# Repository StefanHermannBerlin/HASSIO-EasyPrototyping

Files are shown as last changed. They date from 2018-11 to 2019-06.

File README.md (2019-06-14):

# General Sensor/Actuator for Hassio
 
This readme is organised in three parts:

- Overview
- Building the General Sensor/Actuator
- Configuration

## Overview

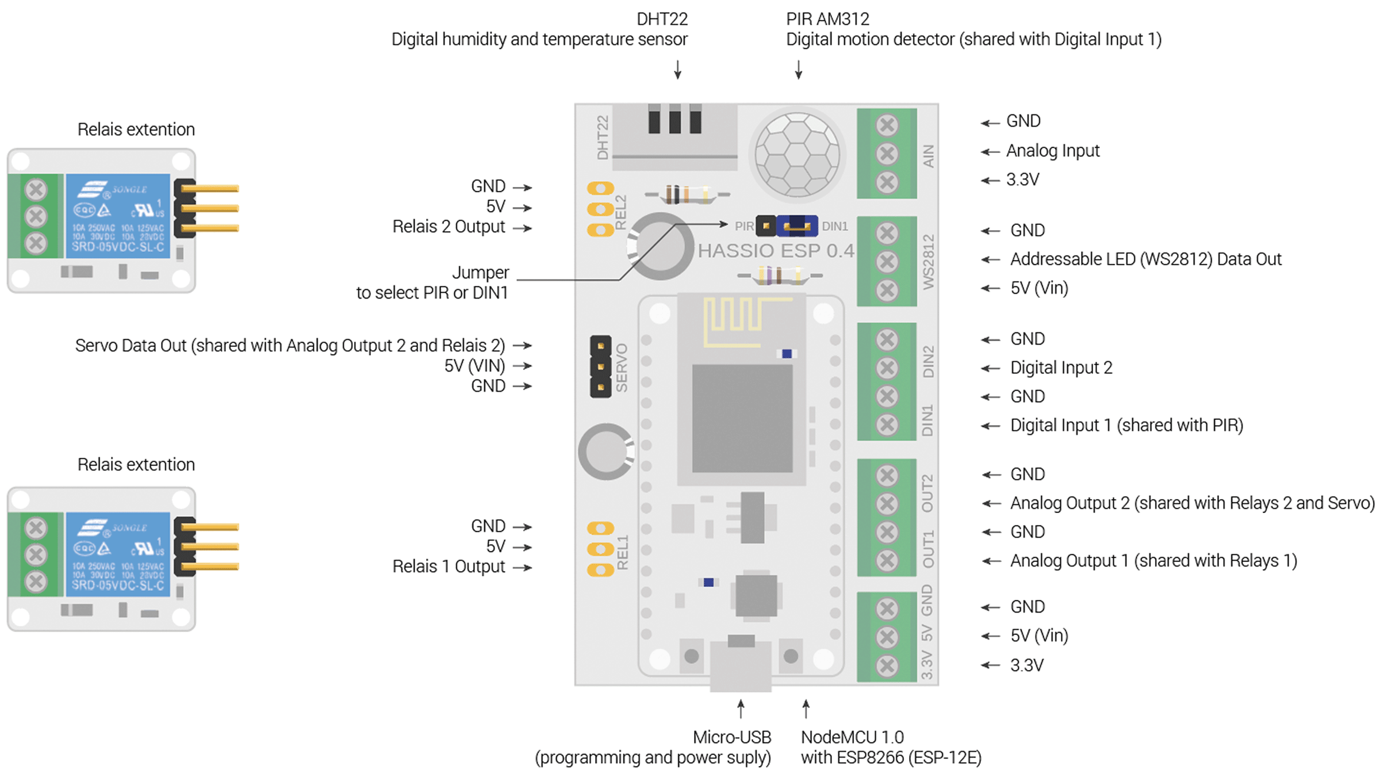
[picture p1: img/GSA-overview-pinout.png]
GSA Pinout


The General Sensor/Actuator (GSA) is a modular device to create functional smart home prototypes to test ideas with users.

It connects to the Home Assistant platform which allows us to prototype smart home applications. Home Assistant can connect to several available devices and makes automation and interoperability possible.

The GSA consists of a NodeMCU, a wifi enabled microcontroller, screw terminals connect sensors and actors to it, a DHT22 temperature and humidity sensor, a PIR sensor (motion sensor), a terminal to connect a servo motor to and two connections for relay modules.

The GSA is powered by a USB power supply.

#### Pins
- 1x Analog input (e.g. light sensors, potentiometers, water sensors)
- 1x WS2812 connector (addressable LEDs)
- 2x Digital input (e.g. buttons, switches, D1 shared through jumper with a digital motion sensor)
- 2x Analog output (PWM, e.g. dimmable lights, motors - can be used as digital outputs to attach Relais extension boards)
- 2x Relais output for extension boards (shared with the analog outputs)
- 1x Servo connector (shared with Analog output 2)

The configuration is mainly done through the firmware, the software running the GSA. The firmware is transferred through the Arduino IDE.

## Building the General Sensor/Actuator

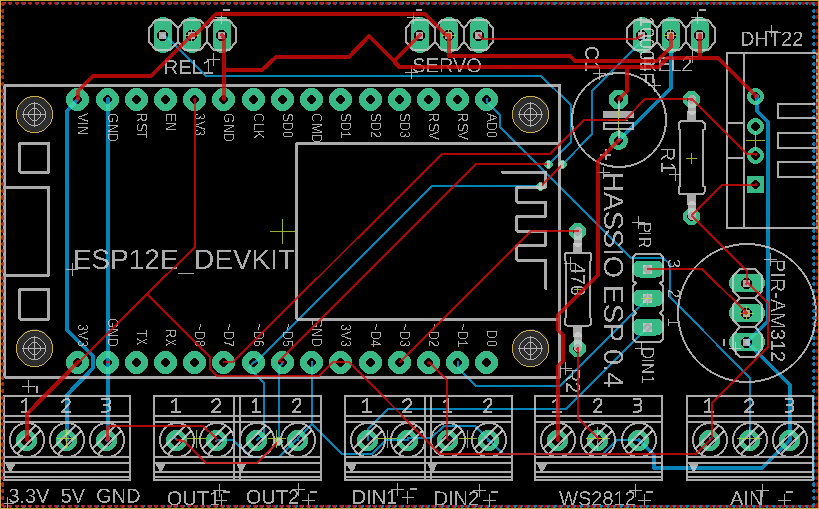
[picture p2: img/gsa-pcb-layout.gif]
GSA PCB Layout


BOM
- 2x 90° 1x3 pin header female
- Resistors: 1x 10k, 1x 470 ohms
- 2x 1x3 pin header male
- 2x 1x15 pin header female
- 2x 1x3 pin header female
- 1x AM312 digital PIR
- 3x screw terminals 3 pins
- 3x screw terminals 4 pins
- 1x DHT22
- 1x electrolytic capacitor 1000uF
- 1x NodeMCU (ESP 12E Module)

Building the GSA is relatively easy. You can order the PCBs using the files contained in the Eagle-folder of this repository from any PCB manufacturing service. Once you have the PCBs solder the following components. I suggest the following order:

- 2x 90° pin headers REL1 and REL2 (2x 1x3 pins female)
- Resistor RE1 with 10k and RE2 with 470 ohms
- Pin headers for SERVO and the jumper (2x 1x3 pins male)
- Pin header for the ESP module (2x 1x15 pins female)
- I recommend to solder a pin header for the digital PIR (1x 1x3 pins female)
- screw terminals (3x 3 pins, 2x 4 pins)
- DHT22
- Capacitor 1000uF

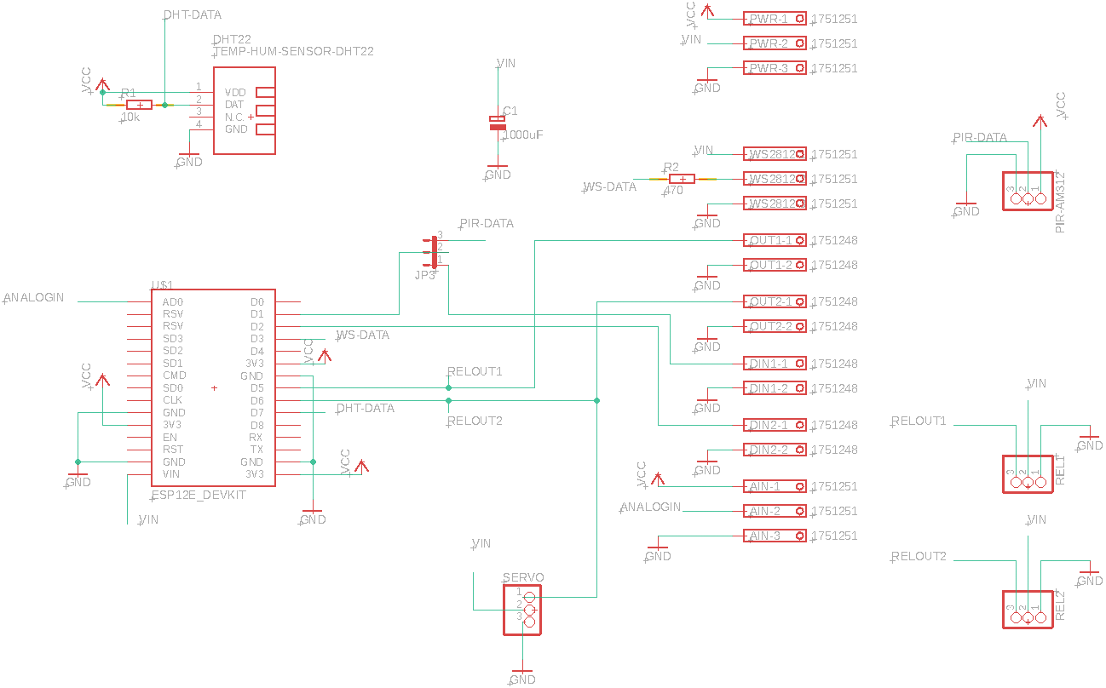
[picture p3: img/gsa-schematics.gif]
GSA Schematics


## GSA configuration

Now, let's connect a General Sensor/Actuator (GSA) to Hass.io. Three simple steps are needed:

Upload a configured firmware to the GSA
Change the configuration.yaml file of your Hass.io installation
Restart Hass.io
1. Upload a configured firmware to the GSA

(I assume you already configured the Arduino software. Otherwise, start here: Set up the Arduino IDE.)

Open the file gsa.ino (You can get it from Github) and fill out the network and security lines. In the device configuration, choose a unique device ID for the GSA. This can be as simple as «LivingRoomFirstFloor».

```
        
/************ Configuration for network and security ******************/

#define wifi_ssid "myWifiName"                        // type your WIFI name in here
#define wifi_password "myWifiPassword"                // your WIFI password
#define mqtt_server "192.168.1.211"                   // the IP of your mqtt broker, e.g. from your Raspbarry Pi running Hassio and the MQTT broker
#define mqtt_user "HassioUserName"                    // your mqtt user name, in the easiest case your Hassio username
#define mqtt_password "HassioPassword"                // your mqtt user password, in the easiest case your Hassio password
#define OTApassword "myFOTApassword"                  // defined by you! and used to upload new firmware from the Arduino-Software (FOTA: Firmware Over The Air)

/************ Device configuration ******************/

#define SENSORNAME "myGeneralSensorActuator007"       // choose an unique device ID for the gsa

boolean digital1opener = true;                        // defines, if digital 1 is opener or closer
boolean digital2opener = true;                        // defines, if digital 2 is opener or closer

boolean digitalIndicatorLED1 = true;                  // if true show indicator light for digital 1
boolean digitalIndicatorLED2 = true;                  // if true show indicator light for digital 1

boolean relay1 = false;                               // if true, relay can be used, if false analog output can be used (if false, don't connect a relais, it will be damaged by the pwm output!!)
boolean relay2 = false;                               // if true, relay can be used, if false analog output can be used (if false, don't connect a relais, it will be damaged by the pwm output!!)

boolean servo = false;                                // if true, servo can be used, if false analog output can be used (if false, don't connect a servo, it may get damaged by the pwm output!!)

boolean showCommunicationFlash = true;                // if true led flashes on data transmission

float diffAnalog = 20;                                // On how much difference should the analog sensore react on?

(this is just a code snipped from the original file gsa.ino)
    
```  
    
You can leave the rest unchanged and simply upload the program to your GSA.

Home Assistant configuration

Open the «configuration.yaml» file in the Configurator. Input the following lines to the light section. (There must only be one «light:» entry. If it already exists, put the child nodes in the existing light section.

```
light:
  - platform: mqtt
    schema: json
    name: "myGSA1 AOut1"  
    state_topic: "myGSA1/aout1"  
    command_topic: "myGSA1/aout1/set"  
    brightness: true   
    rgb: false  
    qos: 0
  - platform: mqtt
    schema: json
    name: "myGSA1 AOut2"  
    state_topic: "myGSA1/aout2"  
    command_topic: "myGSA1/aout2/set"  
    brightness: true   
    rgb: false  
    qos: 0
  - platform: mqtt
    schema: json
    name: "myGSA1 LED"  
    state_topic: "myGSA1"  
    command_topic: "myGSA1/set"  
    brightness: true  
    rgb: true  
    qos: 0  
```    

Now, input the following lines to the sensor section. (There must only be one «sensor:» entry. If it already exists, put the child nodes in the existing sensor section.

```
sensor:
  - platform: mqtt  
    state_topic: "myGSA1"  
    name: "myGSA1 Temperature"  
    unit_of_measurement: "°C"  
    value_template: '{{ value_json.temperature | round(1) }}'  
  - platform: mqtt  
    state_topic: "myGSA1"  
    name: "myGSA1 Humidity"  
    unit_of_measurement: "%"  
    value_template: '{{ value_json.humidity | round(1) }}'  
  - platform: mqtt  
    state_topic: "myGSA1"  
    name: "myGSA1 Analog In"
    value_template: '{{ value_json.analog }}'  

binary_sensor:
  - platform: mqtt
    state_topic: "myGSA1"
    name: "myGSA1 Digital1 In"
    value_template: '{{ value_json.digital1 }}'
    payload_on: "1"
    payload_off: "0"
  - platform: mqtt
    state_topic: "myGSA1"
    name: "myGSA1 Digital2 In"
    value_template: '{{ value_json.digital2 }}'
    payload_on: "1"
    payload_off: "0"
```

Save the configuratoin.yaml and open the groups.yaml file and input the following lines.

```
myGSA1_card: 
  name: Sensor/Actuator 1
  entities: 
    - sensor.myGSA1_temperature
    - sensor.myGSA1_humidity
    - sensor.myGSA1_analog_in
    - binary_sensor.myGSA1_digital1_in
    - binary_sensor.myGSA1_digital2_in
    - light.myGSA1_led
    - light.myGSA1_aout1
    - light.myGSA1_aout2
```

Now reboot your system. After the reboot, you should see the myGSA1 card in Hass.io.

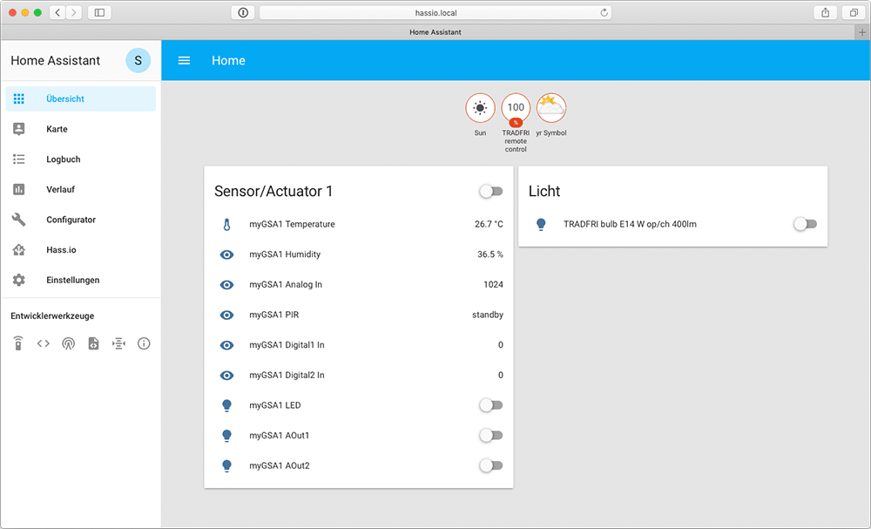
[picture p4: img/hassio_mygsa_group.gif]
GSA Group Card


I hope you find this setup as useful as I do. Have fun!

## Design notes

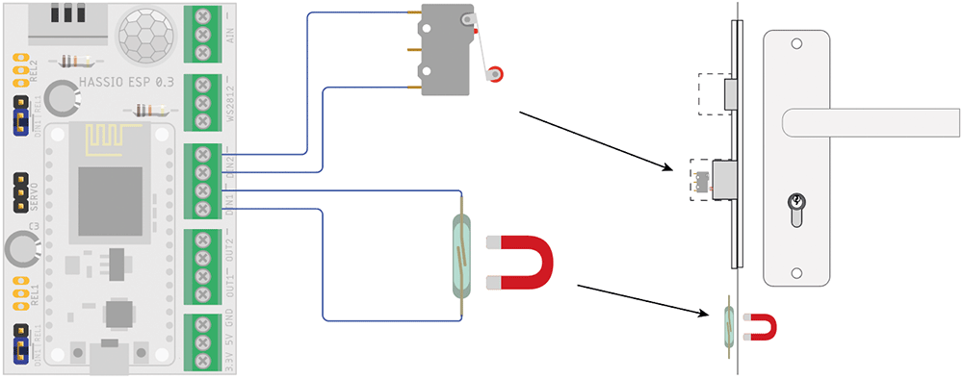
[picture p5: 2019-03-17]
img/esp-door-hardware.gif

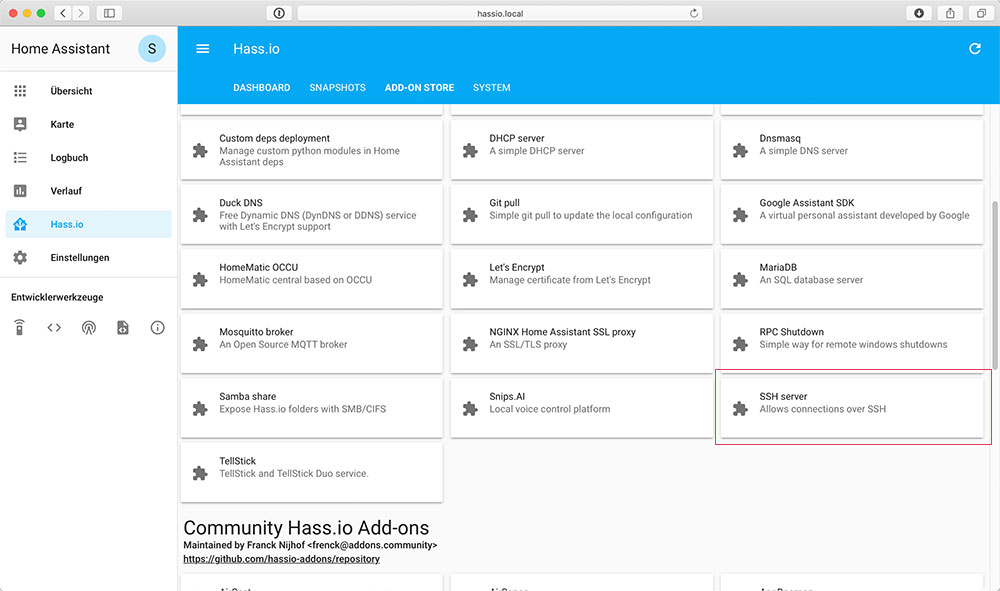
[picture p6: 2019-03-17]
img/hassio_enable_ssh.jpg

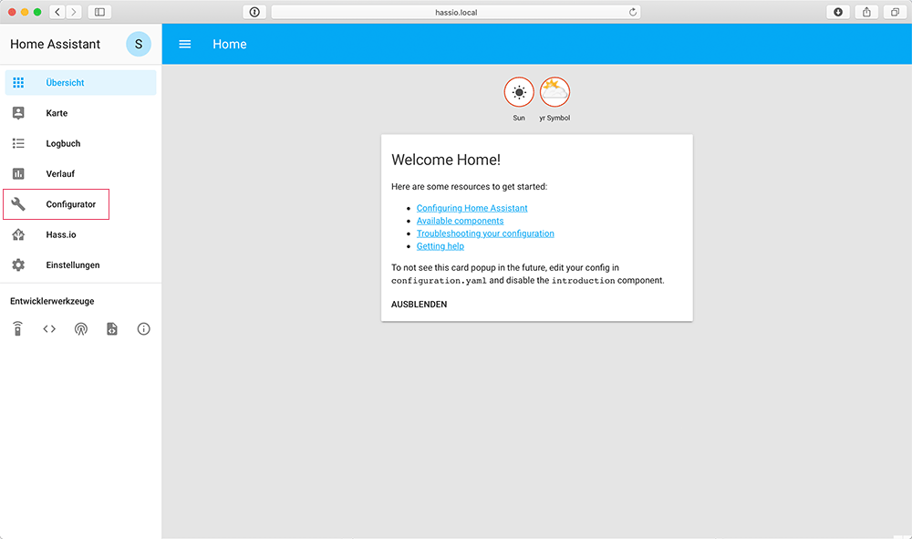
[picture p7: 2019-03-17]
img/hassio-configurator-menu.gif

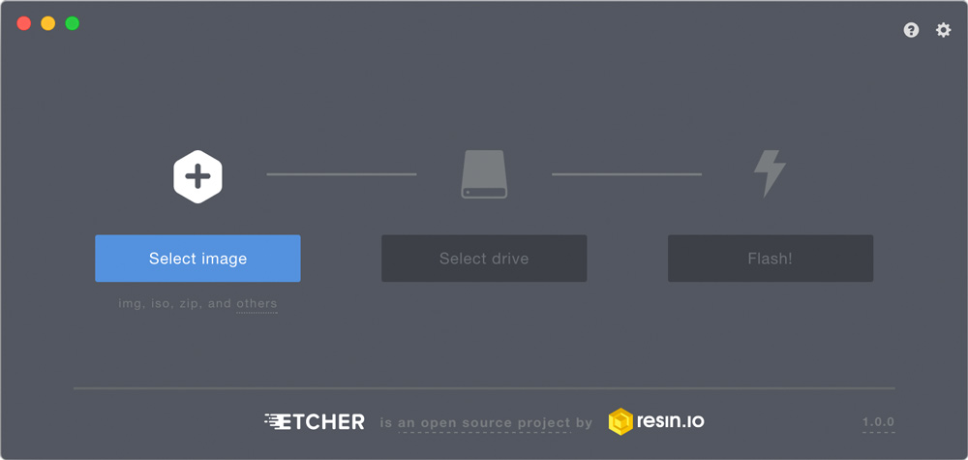
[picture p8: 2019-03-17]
img/screenshot-etcher.jpg

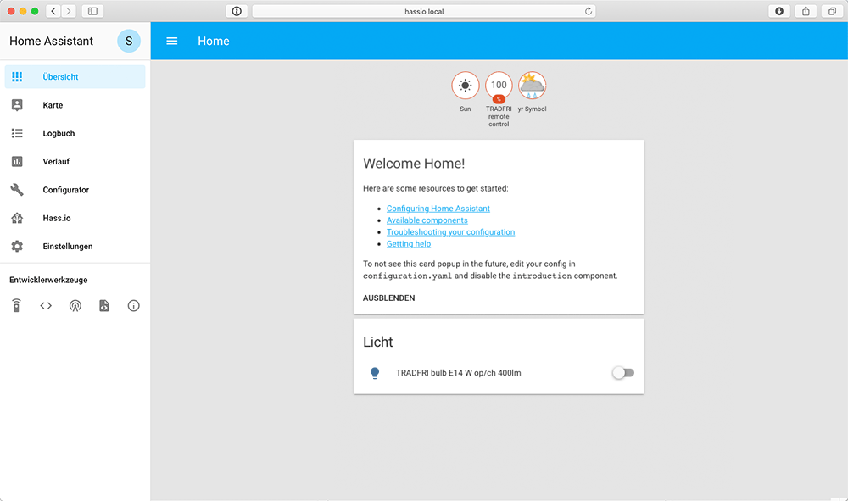
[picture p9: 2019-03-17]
img/hassio_tradfri_card.gif

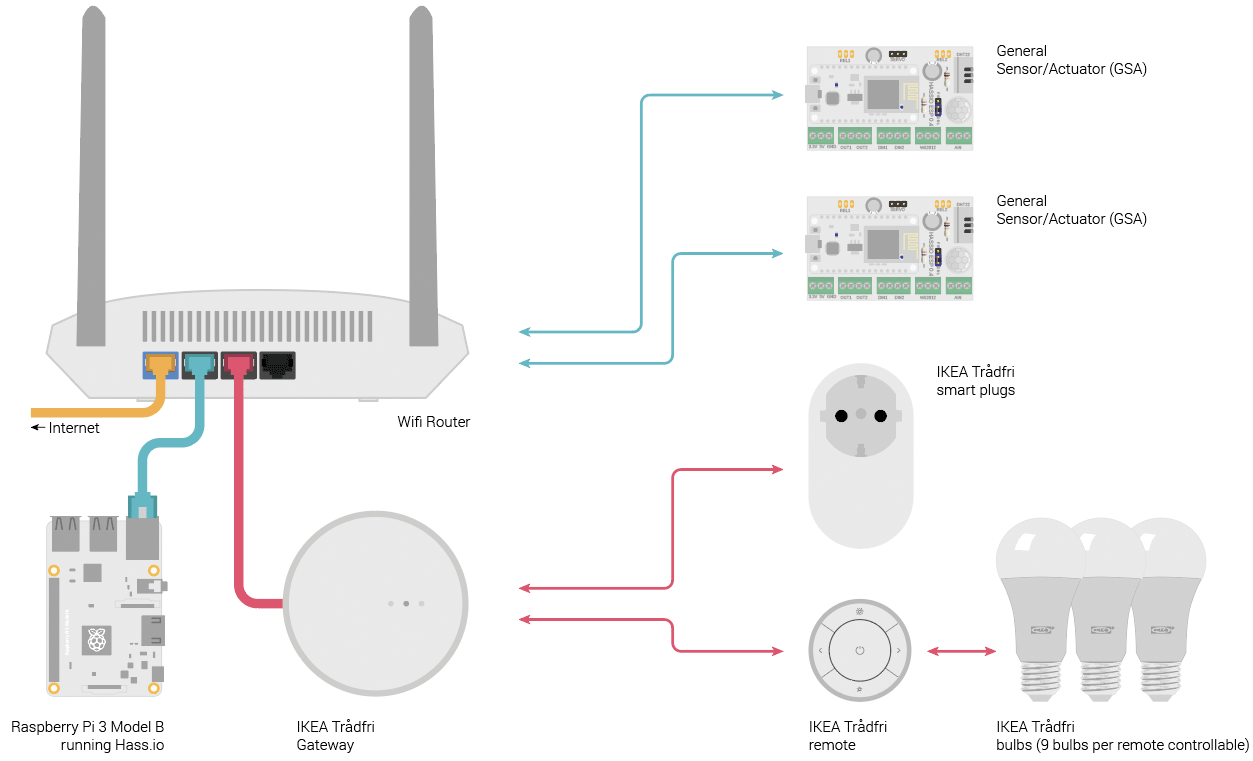
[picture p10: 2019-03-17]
img/prototyping-environment.gif

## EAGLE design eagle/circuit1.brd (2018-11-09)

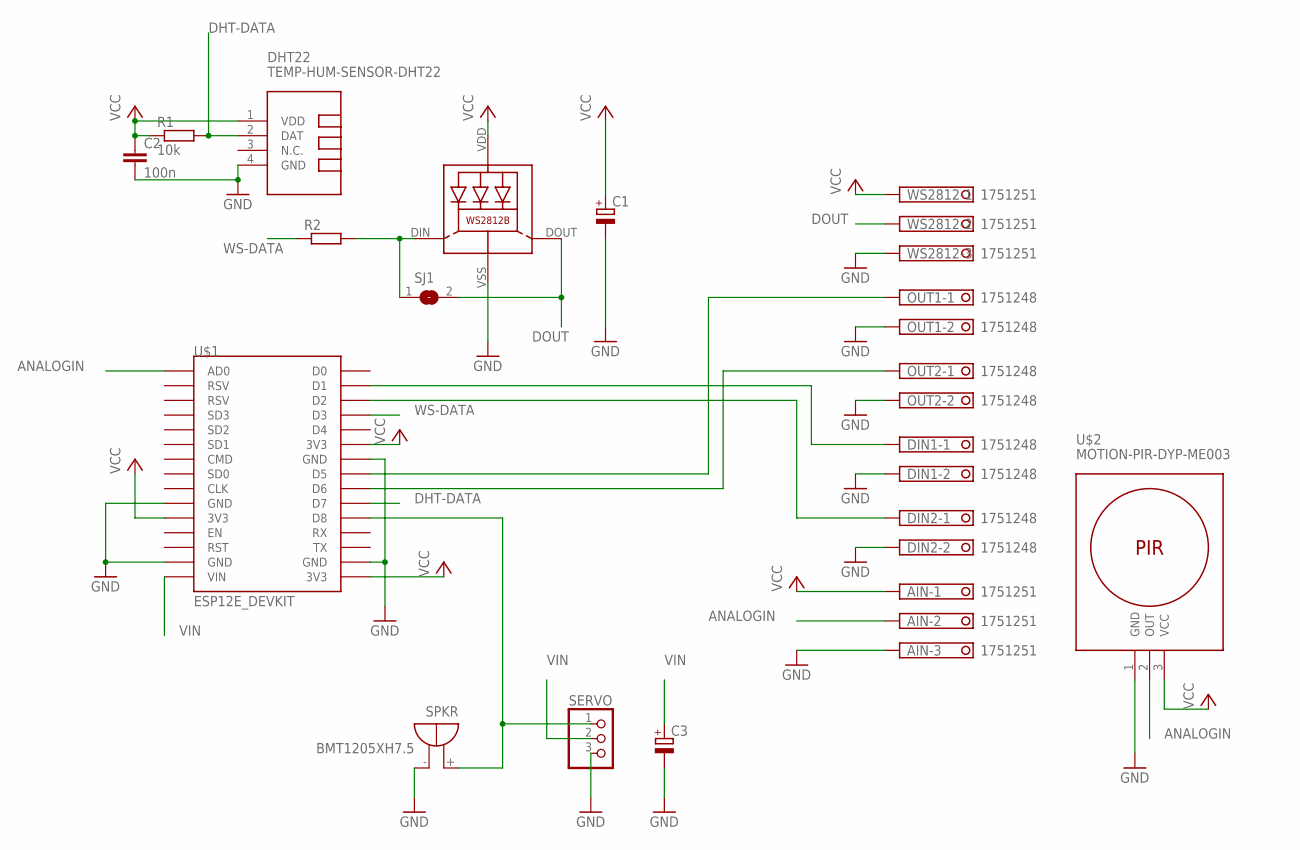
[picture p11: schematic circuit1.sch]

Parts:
AIN: 1751251
C1, C3: CPOL-EUE2.5-7; E2,5-7
C2: 100n; C0805
DHT22: TEMP-HUM-SENSOR-DHT22
DIN1, DIN2: 1751248
LED1: WS2812B
OUT1, OUT2: 1751248
R1: 10k; 0207/10
R2: R0207/10; 0207/10
SERVO: PINHD-1X3; 1X03
SJ1: SJ
SPKR: BMT1205XH7.5
U$1: ESP12E_DEVKIT
U$2: MOTION-PIR-DYP-ME003
WS2812: 1751251

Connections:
ANALOGIN: AIN.2, U$1.AD0, U$2.2 (OUT)
DHT-DATA: DHT22.2 (DAT), R1.2, U$1.D7
DOUT: LED1.DOUT (DO), SJ1.2, WS2812.2
GND: AIN.3, C1.-, C2.2, C3.-, DHT22.4 (GND), DIN1.2, DIN2.2, LED1.VSS (GND), OUT1.2, OUT2.2, SERVO.3, SPKR.-, U$1.GND@0 (GND), U$1.GND@1 (GND), U$1.GND@2 (GND), U$1.GND@3 (GND), U$2.1 (GND), WS2812.3
unnamed: SERVO.1, SPKR.+, U$1.D8
unnamed: OUT1.1, U$1.D5
unnamed: OUT2.1, U$1.D6
unnamed: DIN1.1, U$1.D1
unnamed: DIN2.1, U$1.D2
VCC: AIN.1, C1.+, C2.1, DHT22.1 (VDD), LED1.VDD, R1.1, U$1.3V3@0 (3V3), U$1.3V3@1 (3V3), U$1.3V3@2 (3V3), U$2.3 (VCC), WS2812.1
VIN: C3.+, SERVO.2, U$1.VIN
WS: LED1.DIN (DI), R2.2, SJ1.1
WS-DATA: R2.1, U$1.D3

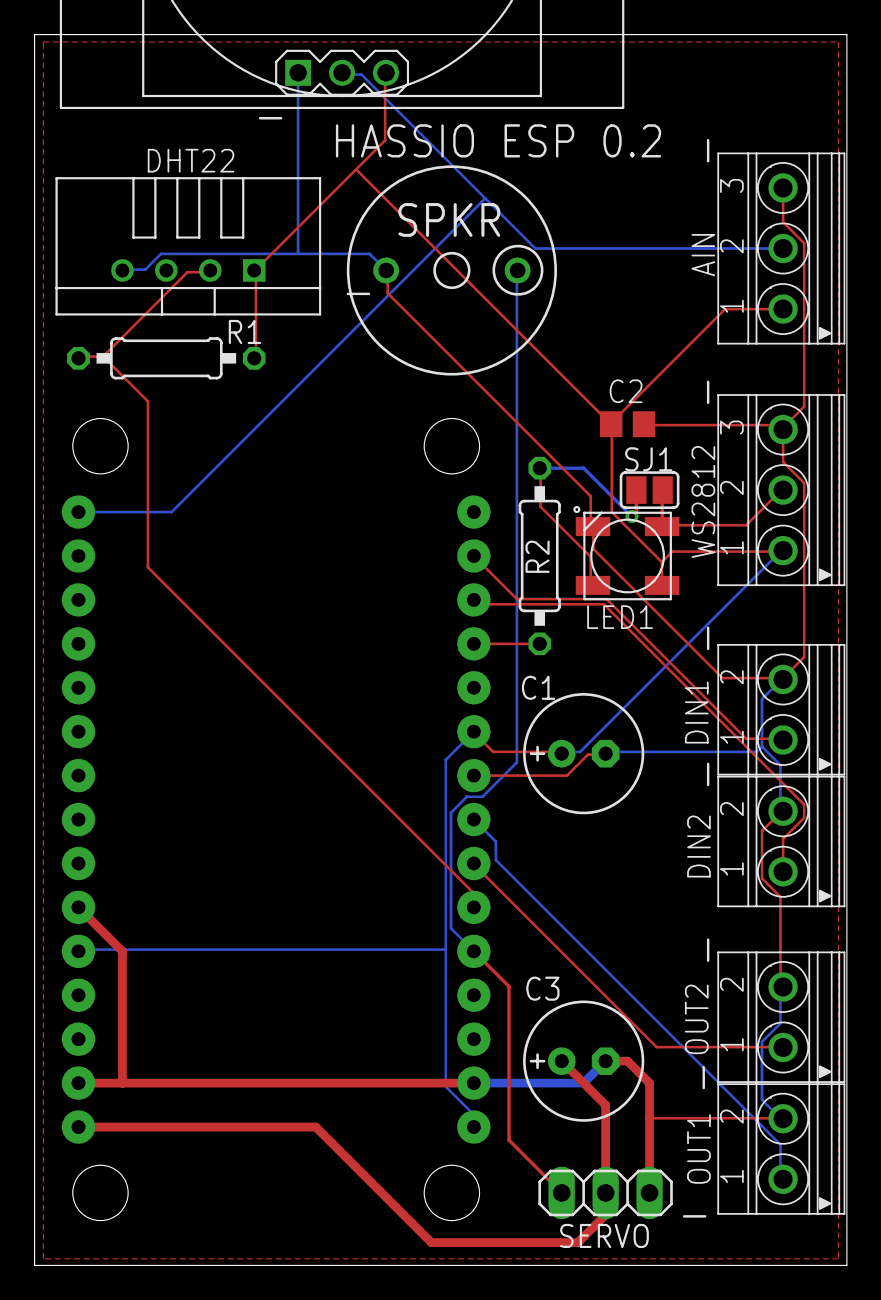
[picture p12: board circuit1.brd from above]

Board: 2 copper layers, 47.0 x 71.2 mm, 18 parts (0 on the bottom side), 13 nets.

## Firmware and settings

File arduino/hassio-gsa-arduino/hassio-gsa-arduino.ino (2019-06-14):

/*
  Thanks much to Bruh Automation, large parts are based on your work.
   
*/



#include <ESP8266WiFi.h>
#include <DHT.h>
#include <PubSubClient.h>
#include <ESP8266mDNS.h>
#include <WiFiUdp.h>
#include <ArduinoOTA.h>
#include <ArduinoJson.h>
#include <Adafruit_NeoPixel.h>
#include <Servo.h> 


/************ Configuration for network and security ******************/

#define wifi_ssid "HAPrototype"                       // type your WIFI name in here
#define wifi_password "prototype"                     // your WIFI password
#define mqtt_server "192.168.1.211"                   // the IP of your mqtt broker, e.g. from your Raspbarry Pi running Hassio and the MQTT broker
#define mqtt_user "stefan"                            // your mqtt user name, in the easiest case your Hassio username
#define mqtt_password "super53cret"                   // your mqtt user password, in the easiest case your Hassio password
#define OTApassword "abcdefghijklmnopqrst"            // defined by you! and used to upload new firmware from the Arduino-Software (FOTA: Firmware Over The Air)

/************ Device configuration ******************/

#define SENSORNAME "myGSA1"                           // unique device ID for the gsa

boolean digital1opener = true;                        // defines, if digital 1 is opener or closer
boolean digital2opener = true;                        // defines, if digital 2 is opener or closer

boolean digitalIndicatorLED1 = true;                  // if true show indicator light for digital 1
boolean digitalIndicatorLED2 = true;                  // if true show indicator light for digital 1

boolean relay1 = false;                               // if true, relay can be used, if false analog output can be used (if false, don't connect a relais, it will be damaged by the pwm output!!)
boolean relay2 = false;                               // if true, relay can be used, if false analog output can be used (if false, don't connect a relais, it will be damaged by the pwm output!!)

boolean servo = true;                                // if true, servo can be used, if false analog output can be used (if false, don't connect a servo, it may get damaged by the pwm output!!)

boolean showCommunicationFlash = false;               // if true led flashes on data transmission

float diffAnalog = 20;                                // On how much difference should the analog sensore react on?



/************* specific mqtt and fota configs - nothing to do from here on  **************************/

#define mqtt_port 1883                                // default 1883 – you don't have to change it
int OTAport = 8266;                                   // default 8266 ;-) – you don't have to change it

/************* MQTT TOPICS (getting assembled later using SENSORNAME)  **************************/

char light_state_topic[80];
char light_set_topic[80];

char aout1_state_topic[80];
char aout1_set_topic[80];

char aout2_state_topic[80];
char aout2_set_topic[80];

const char* on_cmd = "ON";
const char* off_cmd = "OFF";

/**************************** PIN DEFINITIONS ********************************************/

const int RGBPIN = D3;
Adafruit_NeoPixel strip = Adafruit_NeoPixel(1, RGBPIN, NEO_GRB + NEO_KHZ800);

#define PIRPIN    D8  // lieber als output nutzen
#define DHTPIN    D7
#define DHTTYPE   DHT22
#define ANALOGPIN    A0

#define AOUT1     D5
#define AOUT2     D6

#define DIN1      D1
#define DIN2      D2
#define DIN1LED   D4                               // showing DIN1 status directly
#define DIN2LED   D0                               // showing DIN2 status directly

/**************************** SENSOR DEFINITIONS *******************************************/
float analogValue;
int analog;
float calcAnalog;

float diffTEMP = 0.2;
float tempValue;

float diffHUM = 1;
float humValue;

int pirValue;
int pirStatus;
String motionStatus;

char message_buff[100];

int calibrationTime = 0;

const int BUFFER_SIZE = 300;

#define MQTT_MAX_PACKET_SIZE 512

Servo myServo;

/******************************** GLOBALS for fade/flash *******************************/

long lastMsg = 0;
int delayTime = 20000;                                // time until updates are published

byte red = 255;
byte green = 255;
byte blue = 255;
byte brightness = 255;

byte realRed = 0;
byte realGreen = 0;
byte realBlue = 0;

bool stateOn = false;
bool aout1StateOn = false;
bool aout2StateOn = false;

// last states
int digitalIn1State = 0;
int digitalIn2State = 0;
int digitalIn1lastState = 0;
int digitalIn2lastState = 0;


bool startFade = false;
unsigned long lastLoop = 0;
int transitionTime = 0;
bool inFade = false;
int loopCount = 0;
int stepR, stepG, stepB;
int redVal, grnVal, bluVal;

bool flash = false;
bool startFlash = false;
int flashLength = 0;
unsigned long flashStartTime = 0;
byte flashRed = red;
byte flashGreen = green;
byte flashBlue = blue;
byte flashBrightness = brightness;

byte analogOut1Value = 0;
byte analogOut2Value = 0;

WiFiClient espClient;
PubSubClient client(espClient);
DHT dht(DHTPIN, DHTTYPE);

/********************************** Generate Topic Names etc from myThingID *****************************************/
void generateThingID() {
  //snprintf(SENSORNAME, 200, "%s", myThingID);
  //SENSORNAME
  Serial.print("Sensorname: "); Serial.println(SENSORNAME);
  //snprintf(light_state_topic, 200, "%s", myThingID);
  //light_state_topic = SENSORNAME;
  //light_set_topic = String(light_set_topic)+"/set");
  //snprintf(light_set_topic, 200, "%s/%s", myThingID, "set");
  //  light_state_topic = SENSORNAME;
  strcat(light_state_topic, SENSORNAME);
  strcat(light_set_topic, SENSORNAME);
  strcat(light_set_topic, "/set");
  Serial.print("light_state_topic: "); Serial.println(light_state_topic);
  Serial.print("light_set_topic: "); Serial.println(light_set_topic);

  strcat(aout1_state_topic, SENSORNAME);
  strcat(aout1_state_topic, "/aout1");

  strcat(aout1_set_topic, SENSORNAME);
  strcat(aout1_set_topic, "/aout1/set");

  strcat(aout2_state_topic, SENSORNAME);
  strcat(aout2_state_topic, "/aout2");

  strcat(aout2_set_topic, SENSORNAME);
  strcat(aout2_set_topic, "/aout2/set");


  /*  snprintf(aout1_state_topic, 200, "%s/aout1", SENSORNAME);
    snprintf(aout1_set_topic, 200, "%s/aout1/%s", SENSORNAME, "set");

    snprintf(aout2_state_topic, 200, "%s/aout2", SENSORNAME);
    snprintf(aout2_set_topic, 200, "%s/aout2/%s", SENSORNAME, "set");*/
}


/********************************** START SETUP *****************************************/
void setup() {

  Serial.begin(115200);

  pinMode(PIRPIN, INPUT);
  pinMode(DHTPIN, INPUT);
  pinMode(ANALOGPIN, INPUT);
  pinMode(RGBPIN, INPUT);

  pinMode(DIN1, INPUT_PULLUP);
  pinMode(DIN2, INPUT_PULLUP);
  pinMode(DIN1LED, OUTPUT);
  pinMode(DIN2LED, OUTPUT);

  if (relay1 == true) pinMode(AOUT1, OUTPUT);
  if (relay2 == true) pinMode(AOUT2, OUTPUT);

  if (servo == true) {
    
    myServo.attach(AOUT2);
  }

  strip.begin();

  generateThingID();

  delay(10);

  ArduinoOTA.setPort(OTAport);
  ArduinoOTA.setHostname(SENSORNAME);
  ArduinoOTA.setPassword((const char *)OTApassword);

  Serial.print("calibrating sensor ");
  for (int i = 0; i < calibrationTime; i++) {
    Serial.print(".");
    delay(1000);
  }

  Serial.println("Starting Node named " + String(SENSORNAME));


  setup_wifi();

  client.setServer(mqtt_server, mqtt_port);
  client.setCallback(callback);


  ArduinoOTA.onStart([]() {
    Serial.println("Starting");
  });
  ArduinoOTA.onEnd([]() {
    Serial.println("\nEnd");
  });
  ArduinoOTA.onProgress([](unsigned int progress, unsigned int total) {
    Serial.printf("Progress: %u%%\r", (progress / (total / 100)));
  });
  ArduinoOTA.onError([](ota_error_t error) {
    Serial.printf("Error[%u]: ", error);
    if (error == OTA_AUTH_ERROR) Serial.println("Auth Failed");
    else if (error == OTA_BEGIN_ERROR) Serial.println("Begin Failed");
    else if (error == OTA_CONNECT_ERROR) Serial.println("Connect Failed");
    else if (error == OTA_RECEIVE_ERROR) Serial.println("Receive Failed");
    else if (error == OTA_END_ERROR) Serial.println("End Failed");
  });
  ArduinoOTA.begin();
  Serial.println("Ready");
  Serial.print("IPess: ");
  Serial.println(WiFi.localIP());
  reconnect();
}




/********************************** START SETUP WIFI*****************************************/
void setup_wifi() {

  delay(10);
  Serial.println();
  Serial.print("Connecting to ");
  Serial.println(wifi_ssid);

  WiFi.mode(WIFI_STA);
  WiFi.begin(wifi_ssid, wifi_password);

  while (WiFi.status() != WL_CONNECTED) {
    delay(500);
    Serial.print(".");
  }

  Serial.println("");
  Serial.println("WiFi connected");
  Serial.println("IP address: ");
  Serial.println(WiFi.localIP());
}



/********************************** START CALLBACK*****************************************/
void callback(char* topic, byte* payload, unsigned int length) {
  Serial.print("Message arrived [");
  Serial.print(topic);
  Serial.print("] ");

  if (strcmp(topic, light_set_topic) == 0) {
    char message[length + 1];
    for (int i = 0; i < length; i++) {
      message[i] = (char)payload[i];
    }
    message[length] = '\0';
    Serial.println(message);

    if (!processJson(message)) {
      return;
    }

    if (stateOn) {
      // Update lights
      realRed = map(red, 0, 255, 0, brightness);
      realGreen = map(green, 0, 255, 0, brightness);
      realBlue = map(blue, 0, 255, 0, brightness);
    }
    else {
      realRed = 0;
      realGreen = 0;
      realBlue = 0;
    }

    startFade = true;
    inFade = false; // Kill the current fade

    sendState();

  }

  if (strcmp(topic, aout1_set_topic) == 0) {
    char message[length + 1];
    for (int i = 0; i < length; i++) {
      message[i] = (char)payload[i];
    }
    message[length] = '\0';
    Serial.println(message);


    if (!processJsonAout1(message)) {
      return;
    }

    sendStateAnalog1();
  }

  if (strcmp(topic, aout2_set_topic) == 0) {
    char message[length + 1];
    for (int i = 0; i < length; i++) {
      message[i] = (char)payload[i];
    }
    message[length] = '\0';
    Serial.println(message);


    if (!processJsonAout2(message)) {
      return;
    }

    sendStateAnalog2();
  }
}



/********************************** START PROCESS JSON*****************************************/
bool processJson(char* message) {
  StaticJsonBuffer<BUFFER_SIZE> jsonBuffer;

  JsonObject& root = jsonBuffer.parseObject(message);

  if (!root.success()) {
    Serial.println("parseObject() failed");
    return false;
  }

  if (root.containsKey("state")) {
    if (strcmp(root["state"], on_cmd) == 0) {
      stateOn = true;
    }
    else if (strcmp(root["state"], off_cmd) == 0) {
      stateOn = false;
    }
  }

  // If "flash" is included, treat RGB and brightness differently
  if (root.containsKey("flash")) {
    flashLength = (int)root["flash"] * 1000;

    if (root.containsKey("brightness")) {
      flashBrightness = root["brightness"];
    }
    else {
      flashBrightness = brightness;
    }

    if (root.containsKey("color")) {
      flashRed = root["color"]["r"];
      flashGreen = root["color"]["g"];
      flashBlue = root["color"]["b"];
    }
    else {
      flashRed = red;
      flashGreen = green;
      flashBlue = blue;
    }

    flashRed = map(flashRed, 0, 255, 0, flashBrightness);
    flashGreen = map(flashGreen, 0, 255, 0, flashBrightness);
    flashBlue = map(flashBlue, 0, 255, 0, flashBrightness);

    flash = true;
    startFlash = true;
  }
  else { // Not flashing
    flash = false;

    if (root.containsKey("color")) {
      red = root["color"]["r"];
      green = root["color"]["g"];
      blue = root["color"]["b"];
    }

    if (root.containsKey("brightness")) {
      brightness = root["brightness"];
    }

    if (root.containsKey("transition")) {
      transitionTime = root["transition"];
    }
    else {
      transitionTime = 0;
    }
  }

  return true;
}

bool processJsonAout1(char* message) {
  StaticJsonBuffer<BUFFER_SIZE> jsonBuffer;

  JsonObject& root = jsonBuffer.parseObject(message);

  if (!root.success()) {
    Serial.println("parseObject() failed");
    return false;
  }

  if (root.containsKey("state")) {
    if (strcmp(root["state"], on_cmd) == 0) {
      aout1StateOn = true;
      if (root.containsKey("brightness")) {
        if (relay1 == false) analogWrite(AOUT1, root["brightness"]);
        else digitalWrite(AOUT1, HIGH);
      } else {
        if (relay1 == false) analogWrite(AOUT1, 255);
        else digitalWrite(AOUT1, HIGH);
      }
    }
    else if (strcmp(root["state"], off_cmd) == 0) {
      aout1StateOn = false;
      if (relay1 == false) analogWrite(AOUT1, 0);
      else digitalWrite(AOUT1, LOW);
    }
  }

  return true;
}

bool processJsonAout2(char* message) {
  StaticJsonBuffer<BUFFER_SIZE> jsonBuffer;

  JsonObject& root = jsonBuffer.parseObject(message);

  if (!root.success()) {
    Serial.println("parseObject() failed");
    return false;
  }

  if (root.containsKey("state")) {
    if (strcmp(root["state"], on_cmd) == 0) {
      aout2StateOn = true;
      if (root.containsKey("brightness")) {
        if (relay2 == false) {
          if (servo==false) analogWrite(AOUT2, root["brightness"]);
          else myServo.write(map(root["brightness"],0,255,0,170));
        }
        else digitalWrite(AOUT2, HIGH);
      } else {
        if (relay2 == false) {
          if (servo==false) analogWrite(AOUT2, 255);
          else myServo.write(170);
        }
        else digitalWrite(AOUT2, HIGH);
      }
    }
    else if (strcmp(root["state"], off_cmd) == 0) {
      aout2StateOn = false;
      if (relay2 == false) {
        if (servo==false) analogWrite(AOUT2, 0);
        else myServo.write(0);
      }
      else digitalWrite(AOUT2, LOW);
    }
  }

  return true;
}

/********************************** START SEND STATE*****************************************/
void sendState() {
  StaticJsonBuffer<BUFFER_SIZE> jsonBuffer;

  JsonObject& root = jsonBuffer.createObject();

  root["state"] = (stateOn) ? on_cmd : off_cmd;
  JsonObject& color = root.createNestedObject("color");
  color["r"] = red;
  color["g"] = green;
  color["b"] = blue;


  root["brightness"] = brightness;
  root["humidity"] = (String)humValue;
  root["motion"] = (String)motionStatus;
  root["analog"] = (String)analog;
  root["temperature"] = (String)tempValue;
  root["heatIndex"] = (String)calculateHeatIndex(humValue, tempValue);

  root["digital1"] = (String)digitalIn1State;
  root["digital2"] = (String)digitalIn2State;

  char buffer[root.measureLength() + 1];
  root.printTo(buffer, sizeof(buffer));

  Serial.println(buffer);
  client.publish(light_state_topic, buffer, true);
}

void sendStateAnalog1() {
  StaticJsonBuffer<BUFFER_SIZE> jsonBuffer;

  JsonObject& root = jsonBuffer.createObject();

  root["state"] = (aout1StateOn) ? on_cmd : off_cmd;

  root["brightness"] = brightness;

  char buffer[root.measureLength() + 1];
  root.printTo(buffer, sizeof(buffer));

  Serial.println(buffer);
  client.publish(aout1_state_topic, buffer, true);
}

void sendStateAnalog2() {
  StaticJsonBuffer<BUFFER_SIZE> jsonBuffer;

  JsonObject& root = jsonBuffer.createObject();

  root["state"] = (aout2StateOn) ? on_cmd : off_cmd;

  root["brightness"] = brightness;

  char buffer[root.measureLength() + 1];
  root.printTo(buffer, sizeof(buffer));

  Serial.println(buffer);
  client.publish(aout2_state_topic, buffer, true);
}
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
void loop() {
  ArduinoOTA.handle();

  if (!client.connected()) {
    // reconnect();
    software_Reset();
  }
  client.loop();

  long now = millis();

  if (now - delayTime > lastMsg) {                                    // after timeout
    digitalWrite(BUILTIN_LED, LOW);                                   // show that data will get transmitted
    delay(1);
    digitalWrite(BUILTIN_LED, HIGH);
    lastMsg = now;                                                    // timer reset

    getDigitalInStatus();
    sendDigitalInStatus();
  }

  // publish message on state change buttons
  if ((digitalRead(DIN1) != digitalIn1lastState) || (digitalRead(DIN2) != digitalIn2lastState)) {
    getDigitalInStatus();
    sendDigitalInStatus();
  }

  if (!inFade) {

    float newTempValue = dht.readTemperature(); //to use celsius remove the true text inside the parentheses
    float newHumValue = dht.readHumidity();

    //PIR CODE
    pirValue = digitalRead(PIRPIN); //read state of the
    //Serial.print("PIR = ");Serial.println(pirValue);
    if (pirValue == LOW && pirStatus != 1) {
      motionStatus = "standby";
      sendState();
      pirStatus = 1;
    }

    else if (pirValue == HIGH && pirStatus != 2) {
      motionStatus = "motion detected";
      sendState();
      pirStatus = 2;
    }

    delay(100);

    if (checkBoundSensor(newTempValue, tempValue, diffTEMP)) {
      tempValue = newTempValue;
      sendState();
    }

    if (checkBoundSensor(newHumValue, humValue, diffHUM)) {
      humValue = newHumValue;
      sendState();
    }


    int newAnalog = analogRead(ANALOGPIN);

    if (checkBoundSensor(newAnalog, analog, diffAnalog)) {
      analog = newAnalog;
      sendState();
    }

  }

  if (flash) {
    if (startFlash) {
      startFlash = false;
      flashStartTime = millis();
    }

    if ((millis() - flashStartTime) <= flashLength) {
      if ((millis() - flashStartTime) % 1000 <= 500) {
        setColor(flashRed, flashGreen, flashBlue);
      }
      else {
        setColor(0, 0, 0);
        // If you'd prefer the flashing to happen "on top of"
        // the current color, uncomment the next line.
        // setColor(realRed, realGreen, realBlue);
      }
    }
    else {
      flash = false;
      setColor(realRed, realGreen, realBlue);
    }
  }

  if (startFade) {
    // If we don't want to fade, skip it.
    if (transitionTime == 0) {
      setColor(realRed, realGreen, realBlue);

      redVal = realRed;
      grnVal = realGreen;
      bluVal = realBlue;

      startFade = false;
    }
    else {
      loopCount = 0;
      stepR = calculateStep(redVal, realRed);
      stepG = calculateStep(grnVal, realGreen);
      stepB = calculateStep(bluVal, realBlue);

      inFade = true;
    }
  }

  if (inFade) {
    startFade = false;
    unsigned long now = millis();
    if (now - lastLoop > transitionTime) {
      if (loopCount <= 1020) {
        lastLoop = now;

        redVal = calculateVal(stepR, redVal, loopCount);
        grnVal = calculateVal(stepG, grnVal, loopCount);
        bluVal = calculateVal(stepB, bluVal, loopCount);

        setColor(redVal, grnVal, bluVal); // Write current values to LED pins

        Serial.print("Loop count: ");
        Serial.println(loopCount);
        loopCount++;
      }
      else {
        inFade = false;
      }
    }
  }
}




/**************************** START TRANSITION FADER *****************************************/
// From https://www.arduino.cc/en/Tutorial/ColorCrossfader
/* BELOW THIS LINE IS THE MATH -- YOU SHOULDN'T NEED TO CHANGE THIS FOR THE BASICS

  The program works like this:
  Imagine a crossfade that moves the red LED from 0-10,
    the green from 0-5, and the blue from 10 to 7, in
    ten steps.
    We'd want to count the 10 steps and increase or
    decrease color values in evenly stepped increments.
    Imagine a + indicates raising a value by 1, and a -
    equals lowering it. Our 10 step fade would look like:

    1 2 3 4 5 6 7 8 9 10
  R + + + + + + + + + +
  G   +   +   +   +   +
  B     -     -     -

  The red rises from 0 to 10 in ten steps, the green from
  0-5 in 5 steps, and the blue falls from 10 to 7 in three steps.

  In the real program, the color percentages are converted to
  0-255 values, and there are 1020 steps (255*4).

  To figure out how big a step there should be between one up- or
  down-tick of one of the LED values, we call calculateStep(),
  which calculates the absolute gap between the start and end values,
  and then divides that gap by 1020 to determine the size of the step
  between adjustments in the value.
*/
int calculateStep(int prevValue, int endValue) {
  int step = endValue - prevValue; // What's the overall gap?
  if (step) {                      // If its non-zero,
    step = 1020 / step;          //   divide by 1020
  }

  return step;
}

/* The next function is calculateVal. When the loop value, i,
   reaches the step size appropriate for one of the
   colors, it increases or decreases the value of that color by 1.
   (R, G, and B are each calculated separately.)
*/
int calculateVal(int step, int val, int i) {
  if ((step) && i % step == 0) { // If step is non-zero and its time to change a value,
    if (step > 0) {              //   increment the value if step is positive...
      val += 1;
    }
    else if (step < 0) {         //   ...or decrement it if step is negative
      val -= 1;
    }
  }

  // Defensive driving: make sure val stays in the range 0-255
  if (val > 255) {
    val = 255;
  }
  else if (val < 0) {
    val = 0;
  }

  return val;
}

/****reset***/
void software_Reset() // Restarts program from beginning but does not reset the peripherals and registers
{
  Serial.print("resetting");
  ESP.reset();
}

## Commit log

2018-11-09 first push
    [circuit1.brd, circuit1.sch, fritzingSketch.fzz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]
2019-03-17 main update to version 0.41
    [circuit41.brd, circuit41.sch, fritzingSketch.fzz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]
2019-06-14 Readme update
    Readme update, schematics and pcb

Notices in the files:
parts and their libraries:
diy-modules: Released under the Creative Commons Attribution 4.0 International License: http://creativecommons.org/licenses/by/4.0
